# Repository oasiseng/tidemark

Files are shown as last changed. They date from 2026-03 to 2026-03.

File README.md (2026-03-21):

# TideMark™

### Open-source formwork elevation reference stake system

TideMark is a 3D-printable field tool that helps contractors set formwork to the correct elevation — without a surveyor on site. It's a triangular graduated tower that threads onto a printed ground stake, with an eye bolt for stringline attachment and a sliding lock screw for setting target elevation.

Designed by [Oasis Engineering, LLC](https://oasisengineering.com) — a structural engineering firm specializing in wind load analysis, residential permwork, and pre-construction elevation services.

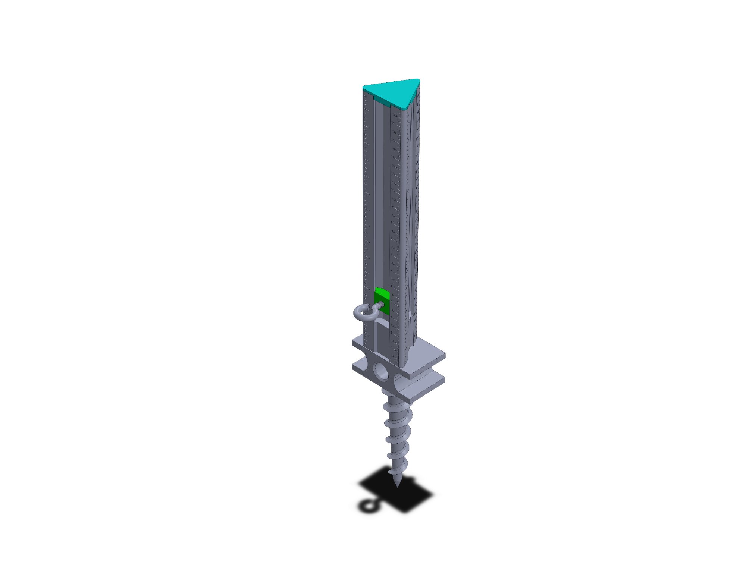
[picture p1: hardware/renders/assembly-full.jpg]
TideMark Assembly


## Build What the Site Actually Needs
In construction and engineering, teams often deliver the medium instead of the outcome.

The medium is familiar: a plan sheet, a note, or an elevation certificate. Those documents matter, but they are not the end goal.

The real goal is simple: the people in the field need to know the exact elevation of grade, formwork, or finished floor so they can build safely, accurately, and confidently — without second-guessing.

TideMark is designed around that reality. It takes the engineer's elevation intent and turns it into a physical, on-site reference that crews can act on immediately. Traditional exhibits and certificates still have their place; TideMark reduces the friction between "information delivered" and "work built correctly."

## The Problem

Contractors building slabs, accessory structures, and ADUs near flood zones need to hit a specific Finished Floor Elevation (FFE). Today, the typical workflow is:

1. Engineer specifies FFE on plans (e.g., "621.25' NAVD88")
2. Contractor stares at the number
3. Contractor eyeballs it with a tape measure off... something
4. Forms get set wrong
5. Everyone has a bad day

There is no affordable, standardized field tool that bridges the gap between a PE's elevation determination and the contractor's formwork.

**TideMark fixes that.**

## The System

TideMark is not just a stake — it's a field reference system with three components:

| Component | What It Does | Where It Lives |
|---|---|---|
| **TideMark Stake** | Physical elevation reference tool | This repo (open source) |
| **Formwork Elevation Reference Exhibit (FERE)** | PE-stamped elevation determination document | [Service from Oasis Engineering](https://oasisengineering.com) |
| **Field Methodology Guide** | Step-by-step photo-documented workflow | [`/docs/field-guide.md`](docs/field-guide.md) |

The stake is the delivery mechanism. The exhibit is the product. The methodology ties them together.

## How It Works

```
┌─────────────────────────────────────────────────────┐
│               ENGINEER SITE VISIT                    │
│                                                      │
│  1. PE performs differential elevation survey at      │
│     project site, establishes reference elevations   │
│                                                      │
│  2. PE drives TideMark ground stakes at strategic    │
│     benchmark locations around proposed structure    │
│                                                      │
│  3. PE threads tower onto each stake, sets lock      │
│     screw to required FFE offset, labels elevation   │
│                                                      │
│  4. PE photographs each installed TideMark stake     │
│     and surrounding site conditions                  │
│                                                      │
│  5. PE produces Formwork Elevation Reference Exhibit  │
│     with benchmark data, photos, and offset dims     │
│                                                      │
│  6. PE delivers exhibit to client — TideMark stakes  │
│     remain installed on site, ready for use          │
└──────────────────────┬──────────────────────────────┘
                       │
                       ▼
┌─────────────────────────────────────────────────────┐
│               CONTRACTOR EXECUTION                   │
│                                                      │
│  7. Contractor locates installed TideMark stakes     │
│     using exhibit site plan and photo references     │
│                                                      │
│  8. Contractor confirms stakes are undisturbed       │
│                                                      │
│  9. Contractor ties stringline to eye bolts —        │
│     the stakes are already set to FFE               │
│                                                      │
│  10. Contractor sets forms to stringline             │
│                                                      │
│  11. Contractor photographs stakes + forms and       │
│      sends to PE for pre-pour verification           │
└─────────────────────────────────────────────────────┘
```

## Assembly

TideMark Assembly

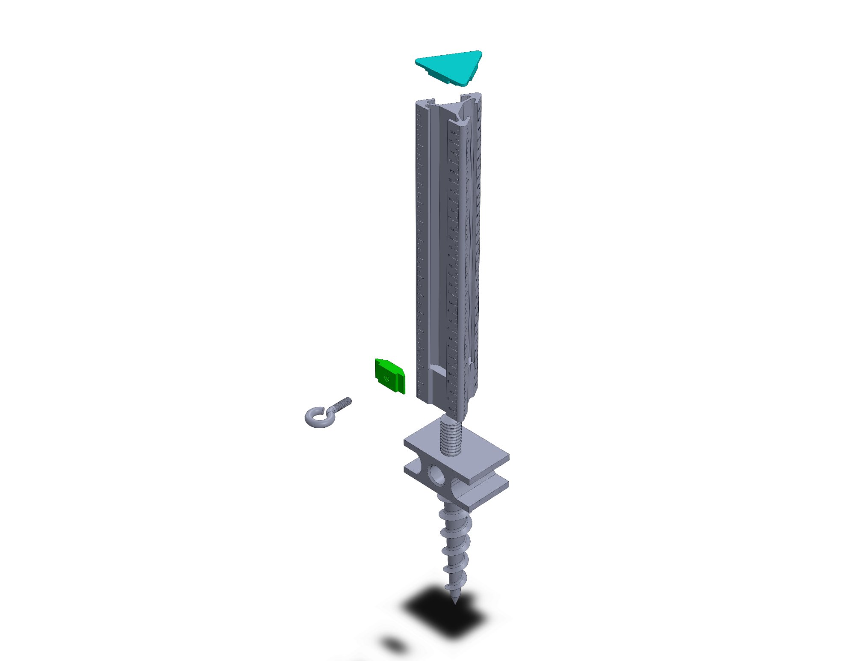
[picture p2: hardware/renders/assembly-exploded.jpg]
TideMark Exploded


## Repository Structure

```
tidemark/
├── README.md                    # You are here
├── LICENSE                      # MIT License
│
├── hardware/
│   ├── stl/                     # Print-ready STL files
│   │   ├── TrianglePiece.STL    # Graduated triangular tower (16")
│   │   ├── GroundStake.STL      # Auger-style ground stake
│   │   ├── HookBolt.STL         # Eye bolt for stringline
│   │   ├── LockBut.STL          # Lock nut for height clamping
│   │   └── TopCap.STL           # Triangular cap (bubble + sticker)
│   ├── source/                  # Editable CAD source files
│   │   └── TideMark.STEP        # Full assembly — all components
│   ├── renders/                 # Product renders
│   │   ├── assembly-full.jpg
│   │   ├── assembly-exploded.jpg
│   │   ├── tidemark-iso-1.jpg
│   │   └── tidemark-iso-2.jpg
│   ├── drawings/                # Engineering drawings
│   ├── BOM.md                   # Bill of materials
│   └── PRINT-SETTINGS.md        # Recommended slicer settings
│
├── docs/
│   ├── field-guide.md           # Step-by-step field usage
│   ├── photo-verification.md    # How to photograph for documentation
│   ├── elevation-basics.md      # FFE, BFE, NAVD88 primer for contractors
│   └── faq.md                   # Common questions
│
├── exhibit/
│   ├── EXHIBIT-SPEC.md          # What goes into a Formwork Elevation
│   │                            #   Reference Exhibit (FERE)
│   ├── SCOPE-OF-SERVICE.md      # Standard scope language for proposals
│   ├── general-notes.md         # Standard general notes for exhibits
│   ├── elevation-control.md     # Elevation control note templates
│   ├── disclaimers.md           # Legal disclaimer language
│   └── examples/
│       └── README.md            # Description of example exhibits
│
├── branding/
│   ├── color-palette.md
│   └── (logo and label templates coming)
│
├── templates/
│   ├── proposal-template.md     # Proposal language for FERE service
│   └── transmittal-template.md  # Client transmittal for exhibit + kit
│
└── CONTRIBUTING.md              # How to contribute
```

## Hardware

### What You Need

| Item | Source | Est. Cost |
|---|---|---|
| TideMark Tower (3D printed, triangular) | Print from `/hardware/stl/` | ~$3 in filament |
| TideMark Ground Stake (3D printed) | Print from `/hardware/stl/` | ~$1.50 in filament |
| TideMark Lock Screw + Nut (3D printed) | Print from `/hardware/stl/` | ~$0.50 in filament |
| Eye bolt, 1" loop | Hardware store or printed | ~$1 |
| Hammer | You already have one | — |
| Sharpie | For labeling | ~$1 |

**Total cost per stake: ~$7.00**

### Print Settings

See [`hardware/PRINT-SETTINGS.md`](hardware/PRINT-SETTINGS.md) for detailed slicer settings.

**Quick reference:**
- **Material:** PETG for tower (UV/impact), PLA for threaded parts (sharper threads)
- **Layer height:** 0.2mm
- **Infill:** 50% gyroid
- **Walls:** 4 perimeters
- **Print plates:** 3 separate plates (tower, hardware, ground stake)
- **Color:** Safety orange or bright yellow for tower, contrasting for lock hardware
- **Avoid:** PLA for the tower (warps in sun, brittle on impact)

### Design Specifications

- **Tower body:** 16" tall, equilateral triangular cross-section, 3" per face
- **Connection:** Female thread (1" × 2") at tower base, mates to male thread on ground stake
- **Graduations:** Embossed inch marks on one face, 1" major / 0.25" minor ticks (1/4" resolution)
- **Stringline attachment:** 1" eye bolt threaded into top of tower
- **Height lock:** Sliding lock screw through tower wall — threaded bolt + nut clamps position
- **Label window:** Flat area on one face for Sharpie notation
- **Branding:** "TIDEMARK" and "OASISENGINEERING.COM" embossed on one face
- **Ground stake:** 8" driven section + 2" handle/grip + 1" male thread (11" total)

## The Exhibit (FERE)

The **Formwork Elevation Reference Exhibit** is the engineering document that makes TideMark useful. Without it, TideMark is just a ruler on a stick. With it, it's a precision field reference system.

A FERE includes:

- **Site plan** with proposed building location and benchmark positions
- **Observed reference elevations** (field-measured benchmarks in NAVD88)
- **FEMA FIRM map exhibit** showing flood zone and BFE (if applicable)
- **Photo exhibits** of physical benchmark locations
- **Foundation detail** showing FFE relationship to existing grade
- **Elevation control notes** specifying FFE, tolerances, and contractor responsibilities
- **General notes and disclaimers** clarifying scope limitations

See [`exhibit/EXHIBIT-SPEC.md`](exhibit/EXHIBIT-SPEC.md) for the full specification.

### What a FERE Is NOT

- ❌ Not a boundary survey
- ❌ Not a topographic survey
- ❌ Not a construction survey
- ❌ Not a substitute for field verification by the contractor

It is a **reference tool** based on limited field observations and publicly available GIS/FEMA data, prepared by a licensed Professional Engineer, intended to assist the contractor in establishing formwork elevation.

## Professional Services

**Need a FERE for your project?**

Oasis Engineering provides Formwork Elevation Reference Exhibits as a standalone service for contractors, builders, and homeowners working on:

- Accessory structures (barndominiums, workshops, detached garages)
- ADUs (accessory dwelling units)
- Residential additions in or near flood zones
- Slab-on-grade structures requiring FFE compliance

**What's included:**
- Site visit or remote assessment (GIS/photo-based)
- PE-stamped Formwork Elevation Reference Exhibit
- TideMark stake kit (4 stakes + lock hardware)
- Field methodology guide

📞 **813-694-8989**
🌐 **[oasisengineering.com](https://oasisengineering.com)**
🌐 **[windcalculations.com](https://windcalculations.com)**

## Contributing

See [`CONTRIBUTING.md`](CONTRIBUTING.md) for guidelines.

We welcome:
- CAD improvements and ergonomic refinements
- Field testing feedback and photos
- Alternative print material recommendations
- Translations of the field guide
- Integration ideas (QR codes, NFC tags, digital level adapters)

## License

The TideMark hardware designs are released under the [MIT License](LICENSE).

**TideMark™** is a trademark of Oasis Engineering, LLC. The open-source hardware license covers the physical designs. The TideMark name, logo, and branding are not included in the open-source license.

The Formwork Elevation Reference Exhibit service, methodology, and associated professional engineering deliverables are proprietary services of Oasis Engineering, LLC.

---

*Designed in Tampa, FL by [Oasis Engineering](https://oasisengineering.com) — Structural Engineering · Wind Load Analysis · Elevation Services*

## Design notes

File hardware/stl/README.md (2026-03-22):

# STL Files

Print-ready STL files for all TideMark v1 components.

## Parts List

| File | Description | Material | Print Orientation |
|---|---|---|---|
| `TrianglePiece.STL` | Graduated triangular tower, 16" tall, 3" faces | PETG (orange) | Vertical, graduation face toward bed |
| `GroundStake.STL` | Auger-style ground stake with threaded top | PETG | Horizontal (layers parallel to length) |
| `HookBolt.STL` | Eye bolt for stringline attachment | PLA | Vertical |
| `LockBut.STL` | Lock nut for height clamping | PLA | Flat |
| `TopCap.STL` | Triangular cap — holds bubble level + sticker | PETG (white or contrasting) | Flat, top face up |

### Triangle2Parts:
| `TrianglePiece_Top.STL` | Graduated triangular tower, 16" tall, 3" faces | PETG (orange) | Vertical, graduation face toward bed | 2 Part Option (Top Portion) for Smaller Printer Plates (fits in 320mm plate)

| `TrianglePiece_Bott.STL` | Graduated triangular tower, 16" tall, 3" faces | PETG (orange) | Vertical, graduation face toward bed | 2 Part Option (Bottom Portion) for Smaller Printer Plates (fits in 320mm plate)

## Full Assembly STEP

The complete assembly as a single STEP file is in `../source/TideMark.STEP`. Open in any CAD program (FreeCAD, Fusion 360, SolidWorks, OnShape) to modify or inspect.

## Print Notes

See `/hardware/PRINT-SETTINGS.md` for detailed slicer settings per part.

**Build volume warning:** The TrianglePiece is 16" (406mm) tall. Check your printer's Z-height. If under 400mm, the tower can be printed in two halves with a threaded joint.

**Critical:** Print the GroundStake with layers running lengthwise (horizontal). Vertical orientation will split along layer lines when hammered.

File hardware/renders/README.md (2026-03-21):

# Renders

Product renders from SolidWorks. Use in README, documentation, and marketing.

| File | Description |
|---|---|
| `assembly-full.jpg` | Full assembly — tower on stake, cap on, hook bolt installed |
| `assembly-exploded.jpg` | Exploded view — all components separated |
| `tidemark-iso-1.jpg` | Isometric view 1 |
| `tidemark-iso-2.jpg` | Isometric view 2 |

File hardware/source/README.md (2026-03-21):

# Source CAD Files

## TideMark.STEP

Full assembly of all TideMark components in a single STEP file. Contains:

- Triangular graduated tower (16" tall, 3" faces)
- Auger-style ground stake with threaded connection
- Eye bolt (hook bolt) for stringline
- Lock nut for height clamping
- Triangular top cap

Open in any CAD program: FreeCAD, Fusion 360, SolidWorks, OnShape, CATIA, Inventor, etc.

## Modifying the Design

1. Open `TideMark.STEP` in your preferred CAD tool
2. Make modifications
3. Export individual parts as STL at 0.1mm tolerance
4. Test print and verify thread engagement, lock nut fit, cap fit
5. Submit PR with updated STEP + STL files and photos of test print

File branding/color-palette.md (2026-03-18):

# TideMark Brand Colors

## Primary Palette

| Color | Hex | Usage |
|---|-----|---|
| **TideMark Orange** | `#FF6B2B` | Primary brand color, stake body, logo accent |
| **Deep Ocean** | `#1A3A4A` | Text, headers, professional contexts |
| **Seafoam** | `#2BBFA0` | Secondary accent, highlights, links |
| **Sand** | `#F5F0E8` | Backgrounds, light surfaces |
| **Coral Red** | `#E8453C` | Target collar color, alerts, CTAs |

## Field Visibility Colors

These are functional colors for the physical product — chosen for visibility on job sites, not aesthetics.

| Part | Color | Hex | Reason |
|---|---|-----|---|
| Tower body | Safety Orange | `#FF6B2B` | OSHA-adjacent visibility, stands out against dirt/concrete/grass |
| Target collar | Signal Red | `#E8453C` | Contrasts against orange tower for photo readability |
| Alternative collar | White | `#FFFFFF` | High contrast option for very bright/dusty sites |
| Cap | Match tower | `#FF6B2B` | Visual unity |

## Typography

| Context | Font | Weight |
|---|---|---|
| Logo / product name | Inter or DM Sans | Bold (700) |
| Headers | Inter | Semi-bold (600) |
| Body text | Inter | Regular (400) |
| Technical / measurements | JetBrains Mono or similar monospace | Regular (400) |

## Logo Usage

The TideMark logo consists of the wordmark "TideMark" with a subtle wave element integrated into the "T" or as an underline element.

- Primary: Deep Ocean on Sand/White background
- Reversed: White on Deep Ocean background
- Icon only: Wave mark in TideMark Orange (for small applications, favicons)

## Embossed Branding on Stakes

For the physical product, branding is embossed (raised or recessed) on the rear face of the tower:

```
TIDEMARK
─────────
OASISENGINEERING.COM
```

- Font: Bold sans-serif, minimum 4mm cap height for legibility
- Depth: 0.6mm emboss/deboss for print clarity
- Location: Rear face of tower, centered, positioned between graduation marks

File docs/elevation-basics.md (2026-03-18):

# Elevation Basics for Contractors

## A Plain-Language Guide to FFE, BFE, NAVD88, and Why It Matters

This guide explains the elevation concepts you'll encounter on a Formwork Elevation Reference Exhibit. No surveying background required.

---

## The Three Numbers You Need to Know

### 1. FFE — Finished Floor Elevation

**What it is:** The elevation of the top surface of your finished slab, measured in feet above sea level.

**Example:** FFE = 621.25' means the top of your finished slab needs to be 621.25 feet above sea level.

**Why it matters:** This is the number the building department checks. If your slab is too low, you fail inspection. If you're in a flood zone, a low slab means the building can flood — and the owner can't get flood insurance.

### 2. BFE — Base Flood Elevation

**What it is:** The elevation that floodwater is expected to reach during a "100-year flood" (a flood that has a 1% chance of happening in any given year).

**Example:** BFE = 620.0' means FEMA predicts floodwater could reach 620 feet above sea level at this location.

**Why it matters:** Building codes require the FFE to be at or above the BFE (and usually above it by a "freeboard" amount — often 1 foot). So if BFE = 620.0' and the jurisdiction requires 1' of freeboard, FFE must be at least 621.0'.

### 3. NAVD88 — North American Vertical Datum of 1988

**What it is:** The reference system that defines what "above sea level" means. It's the ruler that all elevations are measured against.

**Why it matters:** When the exhibit says "621.25' NAVD88," it means 621.25 feet above the NAVD88 reference. This is a nationally standardized system — an elevation of 621.25' NAVD88 in Texas means the same thing as 621.25' NAVD88 in Florida. It's how we compare elevations across the country.

**You don't need to understand the math behind NAVD88.** Just know that all the elevations on your exhibit use this system, and they're all speaking the same language.

---

## How These Numbers Connect

```
BFE (from FEMA) = 620.0'
      +
Freeboard (from local code) = 1.0'
      =
Minimum FFE = 621.0'
      
Your exhibit specifies FFE = 621.25' (with a small safety margin)
```

Your job: set your forms so the top of the finished slab is at 621.25' or higher.

---

## What's a Benchmark?

A **benchmark** is a physical point on the job site with a known elevation. It's the thing you measure from.

Think of it this way: you can't set your forms to "621.25 feet above sea level" by looking at a number. You need a physical reference point — something you can put a tape measure on — that the engineer has already tied to the NAVD88 system.

That's what the benchmarks on your exhibit are. The engineer went to the site (or used GPS/GIS data), established the elevation of specific physical points, and documented them.

**Common benchmarks:**
- A screw or nail the engineer installed in the ground
- An existing concrete pad or curb
- An electrical post base
- A fire hydrant flange

Your exhibit tells you which benchmarks to use, where to find them (with photos), and what their elevation is.

---

## The Offset — Bridging the Gap

Here's the key concept: the **offset** is the vertical distance between a benchmark and your required FFE.

**Example:**
- Benchmark (Screw B) elevation = 621.00'
- Required FFE = 621.25'
- Offset = 621.25 - 621.00 = 0.25 feet = 3 inches

That means: if you measure 3 inches above Screw B, you're at the required FFE.

The TideMark stake makes this easy — you set the collar to 3 inches above zero, and that's your target.

---

## Flood Zones — Quick Reference

Your exhibit includes a FEMA map showing the flood zone. Here's what the common designations mean:

| Zone | What It Means | FFE Required? |
|---|---|---|
| Zone X (unshaded) | Minimal flood risk | Usually no |
| Zone X (shaded) | Moderate flood risk (500-year flood area) | Depends on jurisdiction |
| Zone A | High risk, no published BFE | Yes — community determines BFE |
| Zone AE | High risk, BFE is published | Yes — per BFE + freeboard |
| Zone VE | Coastal high hazard (wave action) | Yes — stricter requirements |

If your project is in Zone A or AE, the FFE requirement is driven by the BFE plus any freeboard the local jurisdiction requires.

---

## Tolerance — How Close Is Close Enough?

The exhibit specifies an elevation tolerance — typically **±0.05 feet** (about 5/8 of an inch).

That means if the required FFE is 621.25', your slab can be anywhere from 621.20' to 621.30' and be within tolerance.

In practice: aim for the specified elevation or slightly above. It's always safer to be a little high than a little low. A slab that's 1/4" too high passes. A slab that's 1/4" too low might not.

---

## Common Questions

**Q: Why can't I just use a laser level?**
A: A laser level tells you that two points are at the same height relative to each other. It doesn't tell you the absolute elevation (height above sea level). You need at least one point with a known NAVD88 elevation — that's your benchmark. From there, a laser level is a great tool for transferring that elevation across the site.

**Q: What if the ground has been graded since the exhibit was prepared?**
A: The benchmarks may no longer be valid if grading has changed the area around them. Call the engineer before proceeding. This is specifically called out in the exhibit's general notes.

**Q: Do I need a surveyor?**
A: The FERE is designed to be used without a surveyor on site. However, if the offset is very large, the site is complex, or you're uncomfortable with the measurements, a surveyor can verify independently. The exhibit is a reference tool — not a replacement for professional survey services if the situation warrants them.

**Q: What's the difference between this exhibit and an Elevation Certificate?**
A: An Elevation Certificate (FEMA Form 086-0-33) is a post-construction document completed by a licensed surveyor that certifies the actual as-built elevation of a structure. The FERE is a pre-construction reference tool that helps you hit the right elevation before you pour. Different documents, different purposes, different times in the project.

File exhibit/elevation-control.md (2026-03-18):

# Elevation Control Notes — Template

## Purpose

The Elevation Control Notes section is the most critical part of the FERE. It tells the contractor:
1. What elevation to hit (FFE)
2. Where to measure from (benchmarks)
3. How accurate they need to be (tolerance)
4. What to do if something doesn't match (call the engineer)

## Template

Customize per project. All [BRACKETED] items are project-specific.

---

### ELEVATION CONTROL NOTES

**FINISHED FLOOR ELEVATION:**
Finished Floor Elevation (FFE) shall be set at **[XXX.XX]' NAVD88** or higher.

**OBSERVED REFERENCE POINTS:**

| ID | Description | Elevation (NAVD88) | Method | Date |
|----|---|---|---|---|
| [A] | [Helical screw head, NE corner of property] | [619.50]' | [RTK GPS] | [MM/DD/YYYY] |
| [B] | [Helical screw head, SE corner of proposed building] | [621.00]' | [RTK GPS] | [MM/DD/YYYY] |
| [C] | [Existing electrical post base] | [619.00]' | [RTK GPS] | [MM/DD/YYYY] |

**BENCHMARK METHODOLOGY:**
[Benchmark elevations were determined via RTK GPS observation on [DATE] using [EQUIPMENT]. / Benchmark elevations were interpolated from [COUNTY] GIS [X]-foot contour data dated [YEAR].]

**ELEVATION OFFSET TABLE (For TideMark Stake Use):**

| Benchmark | Benchmark Elev. | Required FFE | Offset | TideMark Setting |
|---|---|---|---|---|
| [Screw A] | [619.50]' | [621.25]' | [+1.75 ft] | [+21 inches] |
| [Screw B] | [621.00]' | [621.25]' | [+0.25 ft] | [+3 inches] |

> This table directly translates the engineering elevation data into a field-usable TideMark stake setting. The contractor sets the TideMark collar to the inch value shown, at the corresponding benchmark location.

**TOLERANCE:**
Elevation verification tolerance for formwork shall be ±0.05 ft unless noted otherwise.

**CONTRACTOR RESPONSIBILITIES:**
- Contractor shall verify all benchmark elevations prior to use.
- Contractor shall establish final grading, formwork, and elevation control necessary to achieve required FFE.
- Prior to concrete placement, contractor shall provide photo documentation of top-of-form elevations with clear measurement reference for engineer verification.
- Any discrepancies between field conditions and this exhibit shall be reported to the engineer prior to proceeding.

**RECOMMENDED FIELD REFERENCE:**
[Screw B / Benchmark B] may be used as a convenient field reference for establishing minimum FFE, subject to contractor verification. [This benchmark is closest to the proposed building location and provides the smallest offset to FFE.]

---

## Notes on the Offset Table

The **Elevation Offset Table** is what makes the TideMark system work. It converts NAVD88 elevations (which mean nothing to most contractors) into a physical measurement the contractor can execute with the stake.

When preparing this table:
- Always round the inch value conservatively (round up to ensure FFE is met, never round down)
- Include both the decimal-foot offset AND the inch conversion
- Note which benchmark is recommended as the primary field reference
- If the offset exceeds the TideMark stake's measurement range (~24"), note that the contractor may need to establish an intermediate reference point

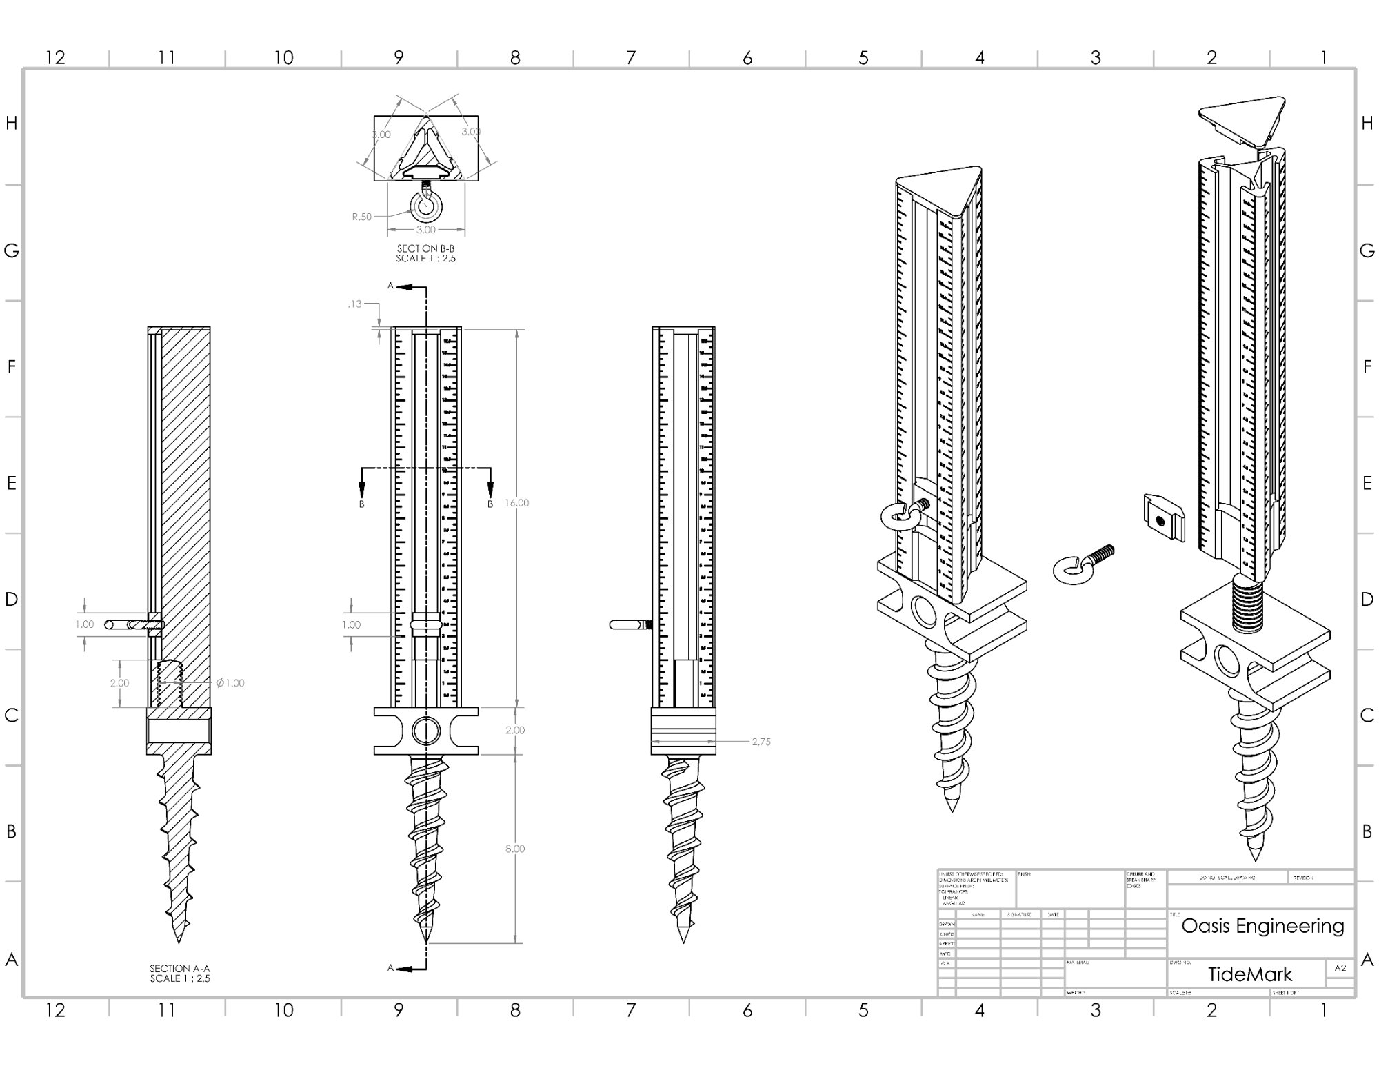
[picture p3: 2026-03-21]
hardware/renders/tidemark-iso-1.jpg

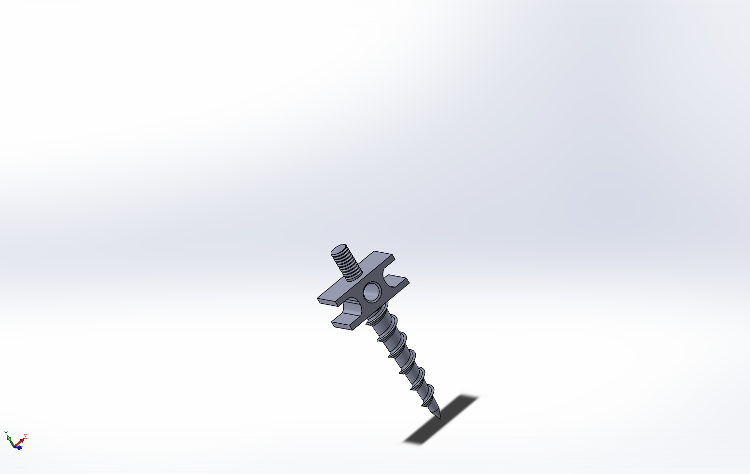
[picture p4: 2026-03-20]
hardware/Renders/Stake_V1.png

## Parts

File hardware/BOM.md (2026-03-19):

# Bill of Materials (BOM)

## TideMark Stake — Single Unit

| # | Item | Specification | Source | Est. Cost |
|---|---|---|---|---|
| 1 | TideMark Tower | 3D printed, PETG, triangular 3"×3"×3" × 16" tall, ~65g | Print from `/hardware/stl/tidemark-tower-v1.stl` | $3.00 |
| 2 | TideMark Ground Stake | 3D printed, PLA/PETG, 8" spike + 2" handle + 1" male thread, ~30g | Print from `/hardware/stl/tidemark-groundstake-v1.stl` | $1.50 |
| 3 | Lock Screw + Nut | 3D printed, PLA, threaded bolt + nut for sliding height lock | Print from `/hardware/stl/tidemark-lockscrew-v1.stl` | $0.50 |
| 4 | Eye Bolt | 1" loop, threaded into top of tower for stringline | Hardware store or 3D printed | $1.00 |
| 5 | Label (optional) | Printed adhesive label from `/branding/label-template.svg` | Inkjet on weatherproof label stock | $0.25 |

**Total per stake: ~$6.25**

## TideMark Contractor Kit (4-Pack)

| # | Item | Qty | Est. Cost |
|---|---|-----|---|
| 1 | TideMark Tower | 4 | $12.00 |
| 2 | TideMark Ground Stake | 4 | $6.00 |
| 3 | Lock Screw + Nut sets | 4 | $2.00 |
| 4 | Eye Bolts (1" loop) | 4 | $4.00 |
| 5 | Adhesive labels | 4 | $1.00 |
| 6 | Instruction card (laminated) | 1 | $2.00 |
| 7 | Canvas zip pouch (branded, optional) | 1 | $5.00 |

**Total per kit: ~$32.00**

## Print Plate Breakdown

The TideMark system is designed to print on **2–3 build plates:**

| Plate | Parts | Material | Notes |
|---|---|---|---|
| **Plate 1** | Triangular tower with graduations | PETG (orange/yellow) | Longest print — tower prints vertically |
| **Plate 2** | Lock screws, lock nuts, eye bolt (if printed) | PLA | PLA prints sharper threads than PETG |
| **Plate 3** | Ground stake | PETG or PLA | Stake prints horizontally |

## Thread Specifications

| Connection | Type | Pitch | Notes |
|---|---|---|---|
| Tower base ↔ Ground stake | Female (tower) / Male (stake) | 3–4mm coarse pitch | Coarse pitch for FDM printability — fine threads strip |
| Lock screw ↔ Tower wall | Through-bolt + nut | 3mm pitch | Bolt passes through hole in tower wall, nut on inside |
| Eye bolt ↔ Tower top | Threaded insert or printed thread | Per eye bolt spec | If using hardware store eye bolt, print matching receiver hole |

## Ground Stake Dimensions

| Segment | Length | Purpose |
|---|---|---|
| Driven section (pointed) | 8" | Penetrates ground |
| Handle/grip section | 2" | Stays above grade, allows hand-tightening or wrench grip |
| Male thread | 1" | Threads into tower base |
| **Total** | **11"** | |

> **Driving the stake:** Use a hammer or small sledge on the handle section. The pointed tip self-starts in most residential soils. For hard or rocky ground, pre-drill a pilot hole with a rebar spike or use a rubber mallet to avoid cracking the printed handle.

## Filament Estimates (Per Complete Stake Assembly)

| Part | Material | Weight | Cost/kg | Cost |
|---|---|---|---|---|
| Tower (PETG) | PETG | ~65g | $20/kg | $1.30 |
| Ground stake (PETG) | PETG | ~30g | $20/kg | $0.60 |
| Lock hardware (PLA) | PLA | ~10g | $18/kg | $0.18 |
| Eye bolt (if printed, PLA) | PLA | ~5g | $18/kg | $0.09 |
| **Total filament** | | **~110g** | | **~$2.17** |

> Hardware store eye bolts are recommended over printed ones for durability under stringline tension. Budget ~$1 per bolt.

## Material Notes

> **Do not use PLA for the tower or ground stake.** PLA deforms at ~60°C (140°F), which is easily reached inside a vehicle or on a sun-exposed job site in Florida/Texas. PETG is the minimum for field use. PLA is acceptable for the lock screw and nut since they don't bear structural loads or sit in direct sun for extended periods.

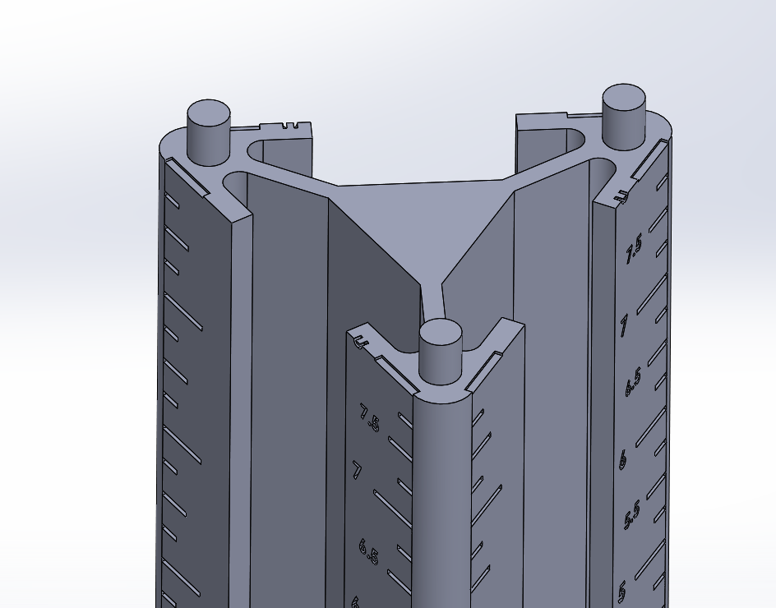
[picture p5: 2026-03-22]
hardware/stl/Triangle2Parts/TrianglePiece_Image.png

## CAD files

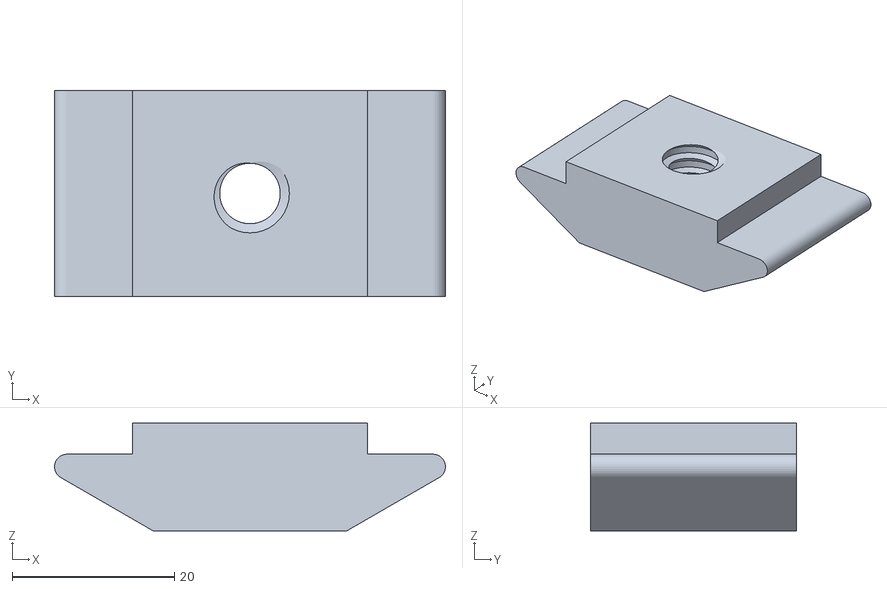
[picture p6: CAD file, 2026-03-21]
hardware/stl/LockBut.STL
48.1 x 25.4 x 13.2

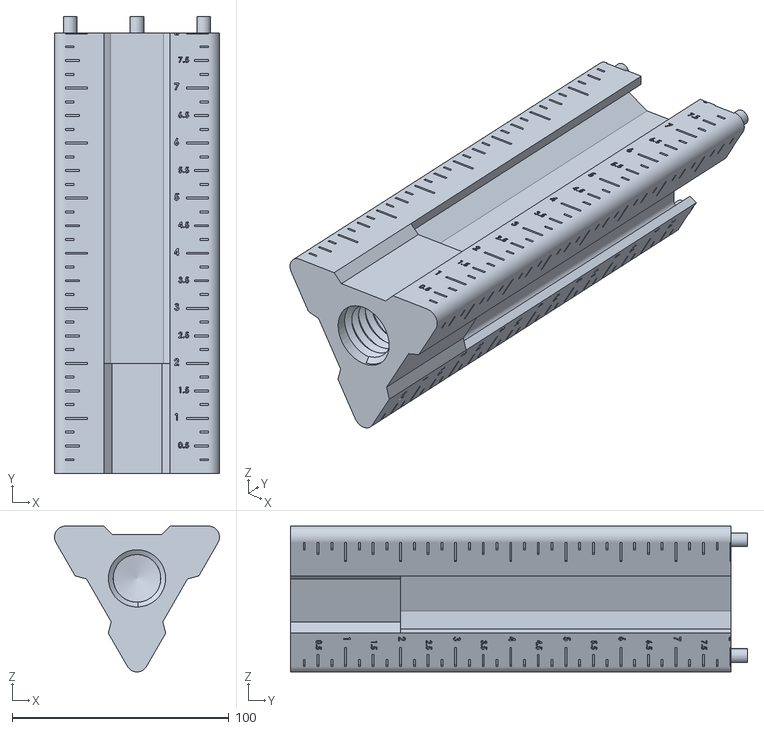
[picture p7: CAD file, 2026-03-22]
hardware/stl/Triangle2Parts/TrianglePiece_Bott.STL
76.1 x 210.8 x 67.3

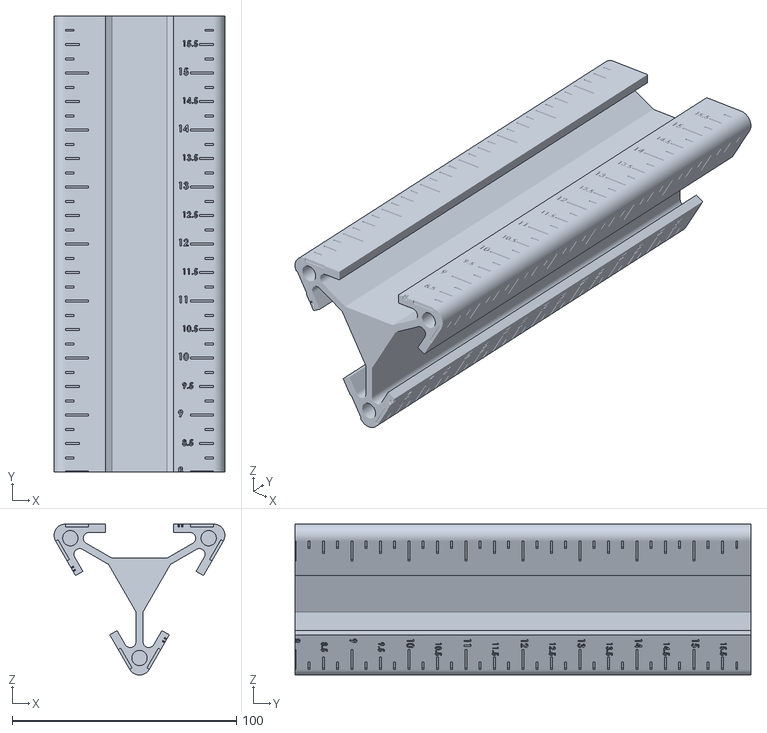
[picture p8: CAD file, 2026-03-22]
hardware/stl/Triangle2Parts/TrianglePiece_Top.STL
76.1 x 203.2 x 67.3

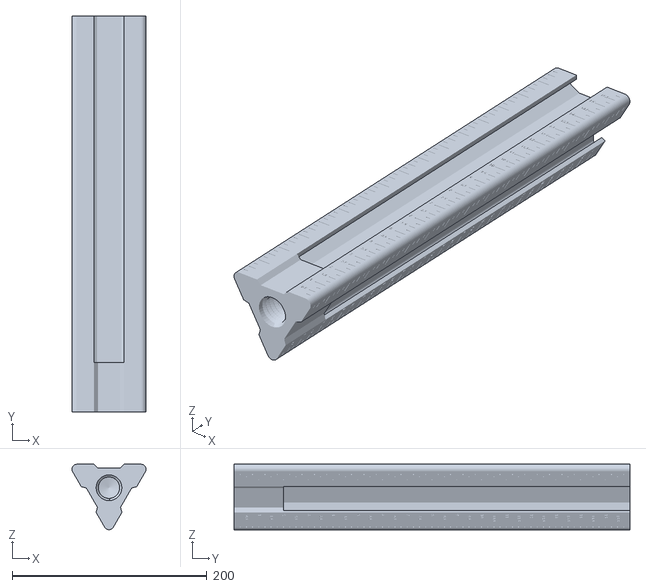
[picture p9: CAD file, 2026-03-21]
hardware/stl/TrianglePiece.STL
76.1 x 406.4 x 67.3

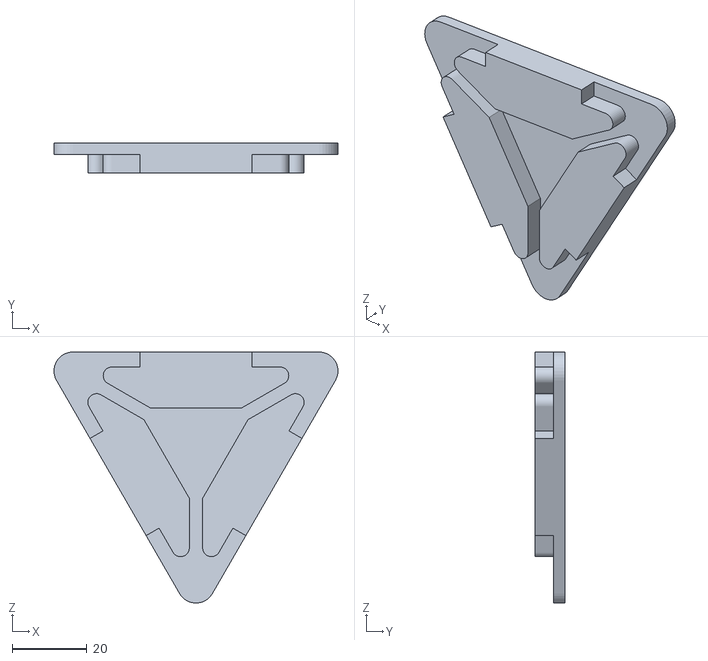
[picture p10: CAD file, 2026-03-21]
hardware/stl/TopCap.STL
76.1 x 8.17 x 67.3

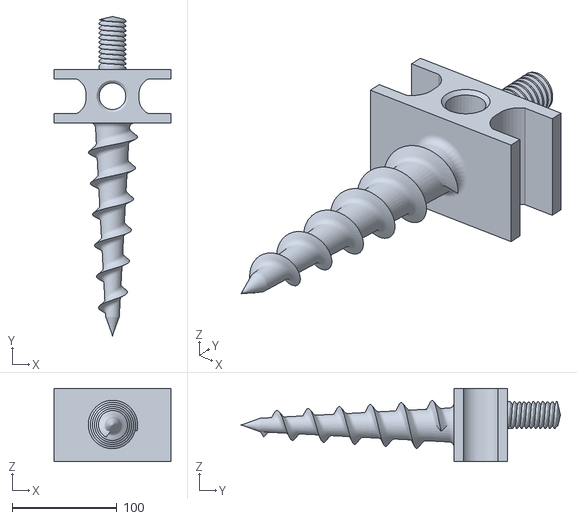
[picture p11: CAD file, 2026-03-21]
hardware/stl/GroundStake.STL
111.8 x 304.8 x 69.8

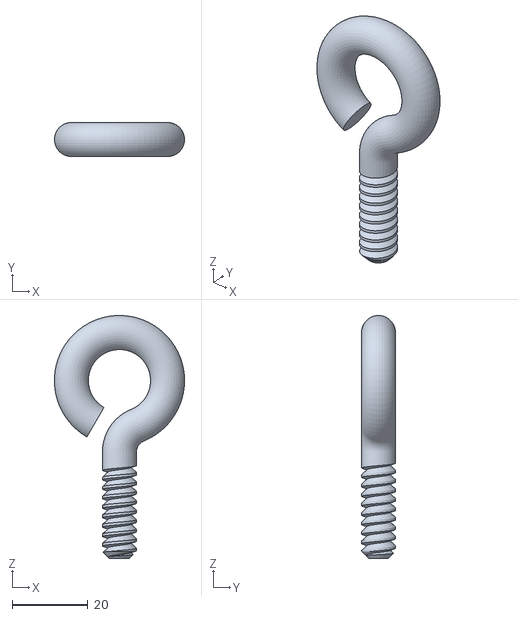
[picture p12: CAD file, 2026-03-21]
hardware/stl/HookBolt.STL
34.4 x 9.00 x 64.2

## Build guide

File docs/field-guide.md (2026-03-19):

# TideMark Field Guide

## For Contractors and Formwork Crews

This guide explains how to use the TideMark elevation reference stake to set formwork to the correct Finished Floor Elevation (FFE) as specified in your Formwork Elevation Reference Exhibit (FERE).

**Read time: 5 minutes. Field setup time: 10 minutes.**

---

## What You Have

Your TideMark kit includes:
- TideMark triangular measuring towers (orange/yellow)
- Ground stakes with threaded tops
- Lock screws and nuts
- Eye bolts for stringline
- This instruction card
- Your PE-stamped Formwork Elevation Reference Exhibit

## What You Need

- Hammer or small sledge
- Stringline
- Your FERE document (the PE-stamped exhibit sheet)
- A phone (for documentation photos)

---

## Step-by-Step Setup

### Step 1: Find Your Benchmarks

Look at your FERE exhibit. It shows benchmark locations on the site plan AND includes photo exhibits of each benchmark. Go find them on site.

Common benchmarks:
- Helical screw heads flush with ground
- Concrete nails in existing hardscape
- Existing electrical post bases
- Permanent site features identified by the engineer

**If you can't find a benchmark, STOP and call the engineer.** Don't guess.

### Step 2: Drive the Ground Stake

Position the TideMark ground stake at or immediately adjacent to the benchmark location. The pointed end goes into the ground. Drive it with a hammer on the handle section until the handle sits at or just above existing grade. The threaded top should be sticking up above the ground.

> **Important:** The ground stake goes NEXT TO the benchmark, not through it. Don't damage the benchmark reference point.

> **Hard soil?** Pre-punch a pilot hole with a rebar spike or use a rubber mallet to avoid cracking the printed handle. Don't hit the threaded top — hammer only on the handle section below the threads.

### Step 3: Thread on the Tower

Thread the TideMark tower onto the ground stake. The female thread at the base of the tower screws onto the male thread on top of the ground stake. Hand-tighten until snug.

The "0" mark on the tower should be at the benchmark elevation. If the benchmark is a screw head at ground level and your stake handle is at grade, the tower's zero is at ground level — which is your benchmark elevation.

### Step 4: Read the Offset from Your Exhibit

Your FERE includes an **Elevation Offset Table** that looks like this:

| Benchmark | Offset | TideMark Setting |
|---|---|---|
| Screw A | +1.75 ft | +21 inches |
| Screw B | +0.25 ft | +3 inches |

Find the benchmark you're using. Read the "TideMark Setting" column. That's the number you set on the stake.

### Step 5: Set and Lock the Height

Slide the lock screw to the inch mark specified in your exhibit. Tighten the knurled lock screw by hand until it's firm — this clamps the tower at the correct height relative to the stake.

Example: If the exhibit says "+21 inches" for Screw A, position the lock indicator at the 21" mark and tighten.

> **The lock screw should be hand-tight, not wrench-tight.** Over-tightening can crack the printed thread. Snug is enough.

### Step 6: Attach the Eye Bolt and Tie Stringline

Thread the eye bolt into the top of the tower if not already installed. Pass your stringline through the eye bolt loop and tie off.

If using multiple TideMark stakes at different benchmarks, the stringline between them should be level (or follow the specified grade) at the required FFE.

### Step 7: Set Forms to the Stringline

Set your formwork to the stringline elevation. The top of your forms should match the stringline.

### Step 8: Document It

**Before you pour, take photos showing:**
- Each TideMark stake with the lock screw position readable
- The stringline in relation to the top of forms
- A tape measure showing the measurement from benchmark to top of form

Send these photos to the engineer for verification before placing concrete. This is required per the exhibit's general notes.

---

## Common Mistakes

| Mistake | What Happens | How to Avoid |
|---|---|---|
| Wrong benchmark | Elevation is off by whatever the difference between benchmarks is | Match the photo exhibit to the physical benchmark — don't assume |
| Reading the wrong column | You set feet instead of inches, or vice versa | Use the "TideMark Setting" column — it's always in inches |
| Benchmark disturbed by grading | Reference elevation is no longer valid | Check benchmarks BEFORE any site grading |
| Ground stake not at grade | Zero reference is shifted | Drive stake so the handle section sits at existing ground level |
| Lock screw not tightened | Tower shifts, elevation drifts | Hand-tighten lock screw until snug — check it before tying string |
| Hammering the threaded top | Damaged threads, tower won't attach | Always hammer on the handle section below the threads |
| Guessing instead of calling | Everything | If in doubt, call the engineer: it's cheaper than tearing out concrete |

---

## When to Call the Engineer

Call **before** proceeding if:
- You can't find a benchmark shown on the exhibit
- The ground conditions look different from the exhibit photos
- The site has been graded since the exhibit was prepared
- The offset seems unreasonably large (>16 inches) or small
- The ground stake won't hold — keeps pulling out or spinning
- Any measurement doesn't feel right

**Phone: [ENGINEER PHONE NUMBER]**

It takes 5 minutes to make a phone call. It takes 5 days to tear out and re-pour a slab.

---

## Care and Storage

- Store TideMark towers out of direct sunlight when not in use (extends life)
- Rinse mud off after use — dried mud obscures graduations
- Clean threads with a brush or compressed air — grit in threads causes binding
- Replace if cracked, warped, or if graduation marks are no longer legible
- Check that the lock screw still clamps firmly — replace if threads are stripped
- The eye bolt loop should be intact with no cracks — replace if bent open or cracked
- Do not use as a pry bar, hammer, or anything other than an elevation reference

---

## Frequently Asked Questions

**Q: Is TideMark a surveying instrument?**
A: No. TideMark is a field reference tool. It helps you execute an elevation that a PE has already determined. It does not measure or establish elevations on its own.

**Q: Can I use TideMark without a FERE exhibit?**
A: You can use it as a general-purpose measuring stake, but you won't know what elevation to set unless a PE has given you that information.

**Q: What if I need to set forms higher than 16 inches above a benchmark?**
A: Contact the engineer. You may need an intermediate reference point established, or a different benchmark may provide a smaller offset. A taller tower variant (v1.1) is planned.

**Q: Why is the tower triangular?**
A: Three reasons: it's more rigid than square or round for the same weight, it self-locates on uneven ground (three points of contact don't wobble), and the flat faces give you a clean surface for graduation marks and branding.

**Q: Can I reuse TideMark stakes on different jobs?**
A: Yes. Clean them, check that the threads engage smoothly, the lock screw clamps, and the graduations are legible. They're good to go.

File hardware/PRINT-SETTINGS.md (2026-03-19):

# Print Settings

## Recommended Slicer Settings

### TideMark Tower (`tidemark-tower-v1.stl`)

| Setting | Value | Notes |
|---|---|---|
| Material | PETG or ASA | See material notes below |
| Nozzle temp | 240°C (PETG) / 250°C (ASA) | Adjust per brand |
| Bed temp | 80°C (PETG) / 100°C (ASA) | |
| Layer height | 0.20mm | Balance of speed and graduation legibility |
| First layer | 0.25mm | Better adhesion |
| Walls/perimeters | 4 | Structural rigidity on triangular faces |
| Top/bottom layers | 5 | Protects graduation face |
| Infill | 50% gyroid | Good omnidirectional strength |
| Print speed | 50mm/s | Slower = better surface on graduation face |
| Supports | None required | Triangular profile is self-supporting |
| Orientation | Vertical, graduation face toward build plate | Best surface quality on measurement face |
| Brim | 8mm recommended | Tall part (16") — brim prevents warping and tip-over |

> **Build volume check:** The tower is 16" (406mm) tall. Verify your printer's Z-height can accommodate this. Most standard printers (Ender 3, Prusa MK3/MK4, Bambu P1/X1) have 250mm+ Z, but 406mm may require a tall-format printer or printing at an angle. If your Z is under 400mm, consider printing in two halves with a threaded or friction-fit joint in the middle.

### TideMark Ground Stake (`tidemark-groundstake-v1.stl`)

| Setting | Value | Notes |
|---|---|---|
| Material | PETG (preferred) or PLA | Needs impact resistance for driving |
| Layer height | 0.20mm | |
| Walls/perimeters | 5 | Extra walls for hammer impact strength |
| Infill | 80% gyroid | Near-solid for driving loads |
| Supports | Minimal (for pointed tip only) | |
| Orientation | Horizontal (on its side) | Layer lines parallel to driving force |

> **Critical: print the ground stake with layers running lengthwise (horizontal orientation).** If printed vertically, layer adhesion is the weak link and the stake will split along layer lines when hammered. Horizontal orientation means the hammer force runs parallel to layers, not perpendicular.

### TideMark Lock Screw + Nut (`tidemark-lockscrew-v1.stl`)

| Setting | Value | Notes |
|---|---|---|
| Material | PLA | PLA prints sharper threads than PETG |
| Layer height | 0.16mm | Finer layers for clean thread profile |
| Walls/perimeters | 4 | |
| Infill | 50% | |
| Supports | None required | |
| Orientation | Bolt vertical (head up), nut flat | |

> **Thread pitch:** Use 3–4mm coarse pitch for all printed threads. Fine threads (≤2mm pitch) will strip on FDM prints. Test thread fit before committing to a full batch — you may need to adjust horizontal expansion in your slicer by -0.1 to -0.2mm for clean thread engagement.

## Material Recommendations

### PETG (Recommended for Tower + Ground Stake)

- Good UV resistance
- Impact resistant — won't shatter when dropped or driven
- Prints easily on most FDM printers
- Withstands vehicle interior temperatures (~85°C glass transition)
- Slight flex prevents brittle cracking
- Available in safety orange and bright yellow

### PLA (Recommended for Threaded Hardware Only)

- Prints the sharpest threads of any common filament
- Rigid — threads hold form under clamping pressure
- Fine for lock screws and nuts (not exposed to sun/heat for long periods)
- ⚠️ **Do not use for tower or ground stake** — deforms at ~60°C

### ASA (Best for Extended Outdoor Use)

- Excellent UV resistance (better than PETG)
- Higher temperature resistance
- Requires enclosed printer (warping sensitive)
- Slightly more brittle than PETG
- Best choice if stakes will be left on site for days/weeks

### Nylon / PA6 (Premium Option)

- Extremely tough and impact resistant
- Excellent chemical resistance
- Requires dry box storage and enclosed printer
- More expensive but nearly indestructible
- Good option for production runs if selling kits

## Color Strategy

| Part | Recommended Color | Why |
|---|---|-----|
| Tower body | Safety orange or bright yellow | Field visibility, OSHA-adjacent |
| Ground stake | Same as tower or black | Visual unity or practical (gets dirty anyway) |
| Lock screw + nut | Red or white | Contrast against tower — visible lock position in photos |
| Eye bolt | Metal (hardware store) or white PLA | Contrast at top for stringline visibility |

> **For photo verification:** high contrast between the tower graduation face and the lock screw position is critical. A red lock screw on an orange tower reads clearly in a job site photo from 15+ feet away.

## Post-Processing

- **Graduation marks:** If embossed marks aren't deep/visible enough, fill recessed numbers with black acrylic paint and wipe excess with a rag. This creates high-contrast filled lettering.
- **Label area:** Light sanding with 220-grit improves Sharpie adhesion on PETG.
- **Thread fit:** Test-thread the tower onto the ground stake before going to the field. If too tight, run the male thread through the female thread a few times to wear in. If too loose, wrap one layer of Teflon tape on the male thread.
- **Eye bolt:** If using a hardware store eye bolt, drill the receiver hole to match and thread or epoxy in place. If printing the eye bolt, reinforce the loop with a small zip tie as a safety backup.

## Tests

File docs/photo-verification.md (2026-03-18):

# Photo Verification Guide

## Why Photo Documentation Matters

Before concrete placement, the contractor must provide photo documentation of top-of-form elevations for engineer verification. This is a requirement of the FERE general notes and serves as the final check before an irreversible pour.

Good photos save phone calls. Bad photos delay pours.

---

## Required Photos (Minimum)

### 1. TideMark Stake Overview

**What to capture:** Full TideMark stake in context, showing:
- Stake location relative to benchmark
- Collar position on the graduated scale
- Stringline connected to the stake

**How to shoot:**
- Stand 6–10 feet away
- Landscape orientation
- Include ground/benchmark in frame
- Collar mark should be readable in the photo

### 2. Collar Close-Up

**What to capture:** Close-up of the collar position on the graduated scale.

**How to shoot:**
- 2–3 feet away
- Eye level with the collar
- Graduation marks clearly visible
- Number at collar position readable

### 3. Tape Measurement Verification

**What to capture:** Tape measure showing distance from benchmark to top of form.

**How to shoot:**
- Hold tape from benchmark reference point to top of form
- Both ends of measurement visible in frame
- Number on tape readable
- Include enough context to identify what you're measuring from and to

### 4. Formwork Overview

**What to capture:** Overall view of the formwork setup showing:
- Stringline in relation to top of forms
- General alignment and condition
- TideMark stake(s) visible in background

**How to shoot:**
- Stand back far enough to see the full form layout
- Stringline should be visible against the sky or a contrasting background

---

## Photo Quality Checklist

Before sending photos to the engineer, verify:

- [ ] Photos are in focus (not blurry)
- [ ] Numbers on tape measure / TideMark graduations are legible
- [ ] Each benchmark used has at least one stake photo
- [ ] Measurement photo shows both reference point and form top
- [ ] Timestamp on photos is current (don't send old photos)
- [ ] Photos are taken in daylight or with adequate lighting

---

## How to Send

Send photos to the engineer via:
- Email (preferred — creates a record)
- Text message (acceptable for quick review)
- Project management platform (if applicable)

Include in your message:
- Project address
- Date of photos
- Which benchmark(s) you measured from
- Your measured elevation offset (in inches)

**Example message:**
> "2798 Robinson Rd — photos from today 3/15/2026. Set forms using Screw B as reference. Collar at +3 inches per exhibit. Tape measurement from screw head to top of form confirms 3 inches. Ready for verification before pour scheduled for 3/17."

---

## What the Engineer Is Looking For

When reviewing your photos, the engineer will verify:

1. **Correct benchmark used** — photos match the benchmark shown in the exhibit
2. **Correct offset** — collar position and tape measurement match the specified offset from the Elevation Offset Table
3. **Consistent measurements** — if multiple benchmarks are used, all offsets are internally consistent
4. **Form condition** — forms appear level, properly braced, and at the correct elevation
5. **No site changes** — ground conditions appear consistent with the exhibit (no unexpected grading or disturbance)

If anything looks off, the engineer will call before clearing the pour.

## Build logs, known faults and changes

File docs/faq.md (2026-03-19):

# Frequently Asked Questions

## About TideMark

**Q: What is TideMark?**
A: TideMark is an open-source 3D-printable elevation reference stake that helps contractors set formwork to the correct Finished Floor Elevation (FFE). It consists of a triangular graduated tower, a threaded ground stake, a lock screw, and an eye bolt for stringline. It's designed to be used with a Formwork Elevation Reference Exhibit (FERE) prepared by a licensed Professional Engineer.

**Q: Is TideMark a surveying tool?**
A: No. TideMark is a field reference tool — a graduated stake with a stringline attachment. It helps you execute an elevation that a PE has already determined. It does not measure or establish elevations on its own.

**Q: Can I sell TideMark stakes?**
A: The hardware designs are MIT-licensed — you can print and sell the physical stakes. However, the "TideMark" name and associated branding are trademarks of Oasis Engineering, LLC and cannot be used without permission. If you want to sell them under your own brand, that's fine.

**Q: What printer do I need?**
A: Any FDM printer with sufficient Z-height. The tower is 16" (406mm) tall — most standard printers (Ender 3, Prusa MK3/MK4, Bambu P1/X1) top out around 250mm Z, which is too short. You'll need a tall-format printer (CR-10, Ender 5 Plus, Voron 350, or similar) OR print the tower in two 8" halves that thread together (planned v1.1 feature). The ground stake and lock hardware fit on any printer.

**Q: Why is it triangular?**
A: Three reasons. First, a triangular cross-section is inherently more rigid than rectangular for the same wall thickness — it resists bending and twisting better. Second, three points of contact mean the tower won't wobble on uneven ground. Third, the flat faces provide clean surfaces for graduation marks, branding, and label windows — one function per face.

**Q: Why not injection mold these?**
A: At the volumes we're talking about (tens to hundreds per year, not thousands), 3D printing is more economical and allows rapid design iteration. If demand grows to thousands of units, injection molding becomes viable — the design is intentionally simple enough to mold.

---

## About the FERE Service

**Q: What is a Formwork Elevation Reference Exhibit?**
A: A PE-stamped document that tells the contractor what elevation to build to, where to measure from, and provides the reference framework to execute it in the field. It's a pre-construction elevation determination for FFE purposes.

**Q: Who needs a FERE?**
A: Contractors building slab-on-grade structures (accessory buildings, ADUs, garages, workshops) in or near flood zones where the building department requires FFE documentation but a full survey isn't justified by the project scope.

**Q: How is this different from a topographic survey?**
A: A topo survey maps the entire site with precision. A FERE establishes a few key reference points and tells the contractor what to do with them. It's faster, cheaper, and sufficient for the specific purpose of setting formwork elevation.

**Q: How much does a FERE cost?**
A: Typically $600–$1,800 depending on whether a site visit is included and whether a TideMark kit is bundled. See the exhibit specification for pricing guidance.

**Q: Can any PE prepare a FERE?**
A: Yes. The FERE methodology documented in this repository can be used by any licensed Professional Engineer. The templates, notes, and disclaimers are provided as a starting point. Each PE is responsible for their own professional judgment and compliance with their state's licensing requirements.

---

## Field Use

**Q: What if my offset is more than 16 inches?**
A: The standard TideMark tower measures up to 16 inches. If your offset exceeds this, contact the engineer — you may need an intermediate reference point, a different benchmark, or a taller tower variant.

**Q: Can I use TideMark without a FERE?**
A: You can use it as a general-purpose measuring stake with stringline attachment, but without a PE's elevation determination, you won't know what elevation to set.

**Q: What if I can't find the benchmark?**
A: Stop and call the engineer. Do not estimate or guess. The benchmark may have been disturbed by site activity — the engineer needs to know.

**Q: Does TideMark work on slopes?**
A: Yes, but the ground stake must be driven plumb (vertical), not perpendicular to the slope surface. The graduations assume a vertical orientation.

**Q: Can I leave TideMark stakes in the ground permanently?**
A: The ground stake can stay, but the printed tower should be removed after formwork is set. UV exposure will degrade PETG over weeks/months. Unthread the tower, clean it, and store it for the next job.

**Q: The threads are stiff / won't engage. What do I do?**
A: Clean both threads with a brush — dirt and grit cause binding. If still stiff, thread them together and apart a few times to wear in. If the male thread is slightly oversized (common with FDM), lightly sand the outer diameter with 220-grit. A wrap of Teflon tape can also smooth engagement.

---

## Technical

**Q: Why printed threads instead of metal hardware?**
A: Printed threads keep the entire system self-contained and 3D printable — no hardware store run required (except the optional eye bolt). Coarse-pitch printed threads (3–4mm pitch) are surprisingly strong and hold up well for this application. The lock screw sees minimal load, and the tower-to-stake connection is hand-tight only.

**Q: What thread pitch should I use?**
A: 3–4mm coarse pitch for all connections. Fine threads (≤2mm) strip easily on FDM prints. The exact pitch isn't critical as long as the tower and stake match — they're always used as a set.

**Q: Can I modify the design?**
A: Yes — that's why it's open source. STEP files are provided for editing in any CAD program. See CONTRIBUTING.md for guidelines on submitting improvements back to the project.
